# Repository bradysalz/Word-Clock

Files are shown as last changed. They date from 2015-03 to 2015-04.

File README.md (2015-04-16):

# Word-Clock
MSP430 based Word Clock for my GE423 HW Project. Decided to make it more of a "word search" than a simple light up clock. Tells the time in five minute intervals. 

## Description
First thing to do is program the init script for the RTC. A backup coin cell battery will make sure it shouldn't need to be re-calibrated for another 15 years (approximate). In normal mode, the MSP430 wakes from sleep and pings the RTC approximately every minute. This occurs by doing several I2C register reads from the device. Each of the "words" (listed below) is an LED load with one LED per letter, and the entire word is turned on/off by a transistor (n-channel FET). All of the 21 words' transistor gates are driven by three 8-bit daisy-chained serial-parallel shift registers. Once the RTC data is parsed, it is converted and shifted out to light up the appropriate phrasing. 

We also have a button available on the MSP430 that will open and close shades on the front of the clock via two servo motors. I eventually plan to automate this based on a custom alarm or light sensor. 

### Words
- Minutes
    - Five
    - Ten
    - Quarter
    - Twenty
    - Half
        
+ Phrases
    + Past
    + To
    + It Is
    + O Clock

As well as the hours One through Twelve. 

### To Do
- [x] Outline letters
- [x] Design Schematic
- [x] Design PCB
- [x] Code MSP430 RTC reads
- [x] Code MSP430 shift register writes
- [x] Code MSP430 servo drivers
- [x] Design physical enclosure
- [ ] Build physical enclosure
- [ ] Wire LEDs/resistors
- [ ] Add curtains

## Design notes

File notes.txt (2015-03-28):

total: 
21 'phrases'
91 letters
5 minute intervals (5/10/15/20/25/30) [+1 for none, +1 for 20+5]
12 hour intervals

longest sentence:
it is twenty five past eleven o clock
30 LED's simulataneously

max power budgeting:
LED: 30 x 0.03 A = 0.9
uC: 100mA~

bought:
RTC [BQ32002]
32.168kHz crystal
3.3v regulator 
shift registers 
FETs
usb connector

need2buy:
resistors
headers

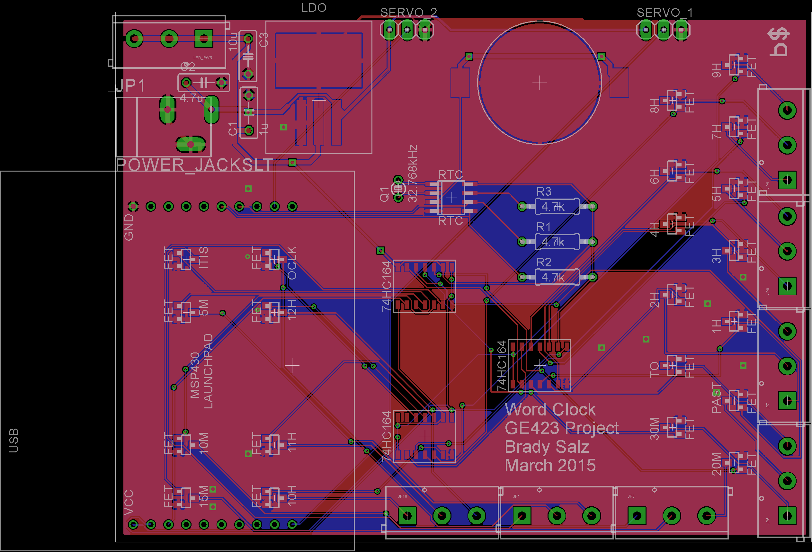
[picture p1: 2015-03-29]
hardware/WordClock_PCB.png

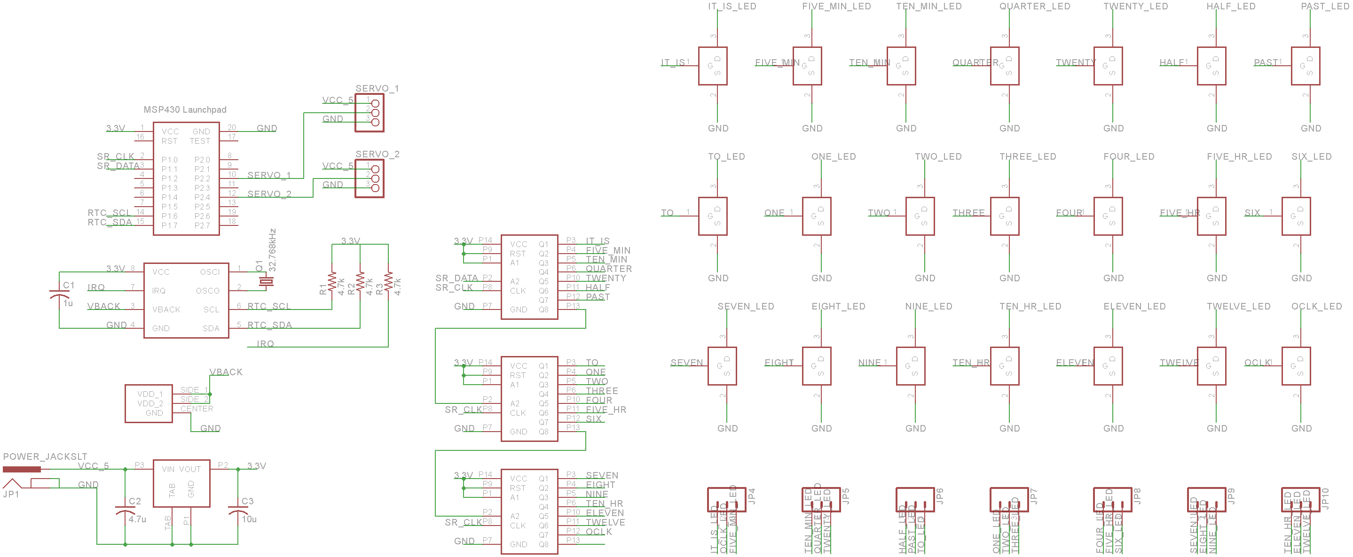
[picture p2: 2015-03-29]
hardware/WordClock_SCH.png

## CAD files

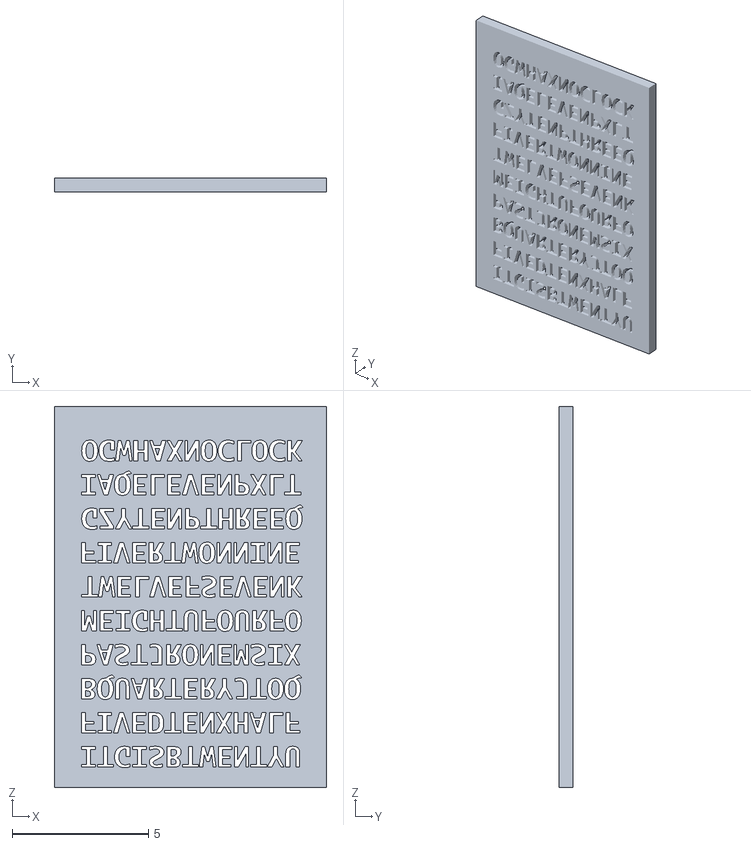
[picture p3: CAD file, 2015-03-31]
mechanical/word_clock.stl
10.0 x 0.5 x 14.0

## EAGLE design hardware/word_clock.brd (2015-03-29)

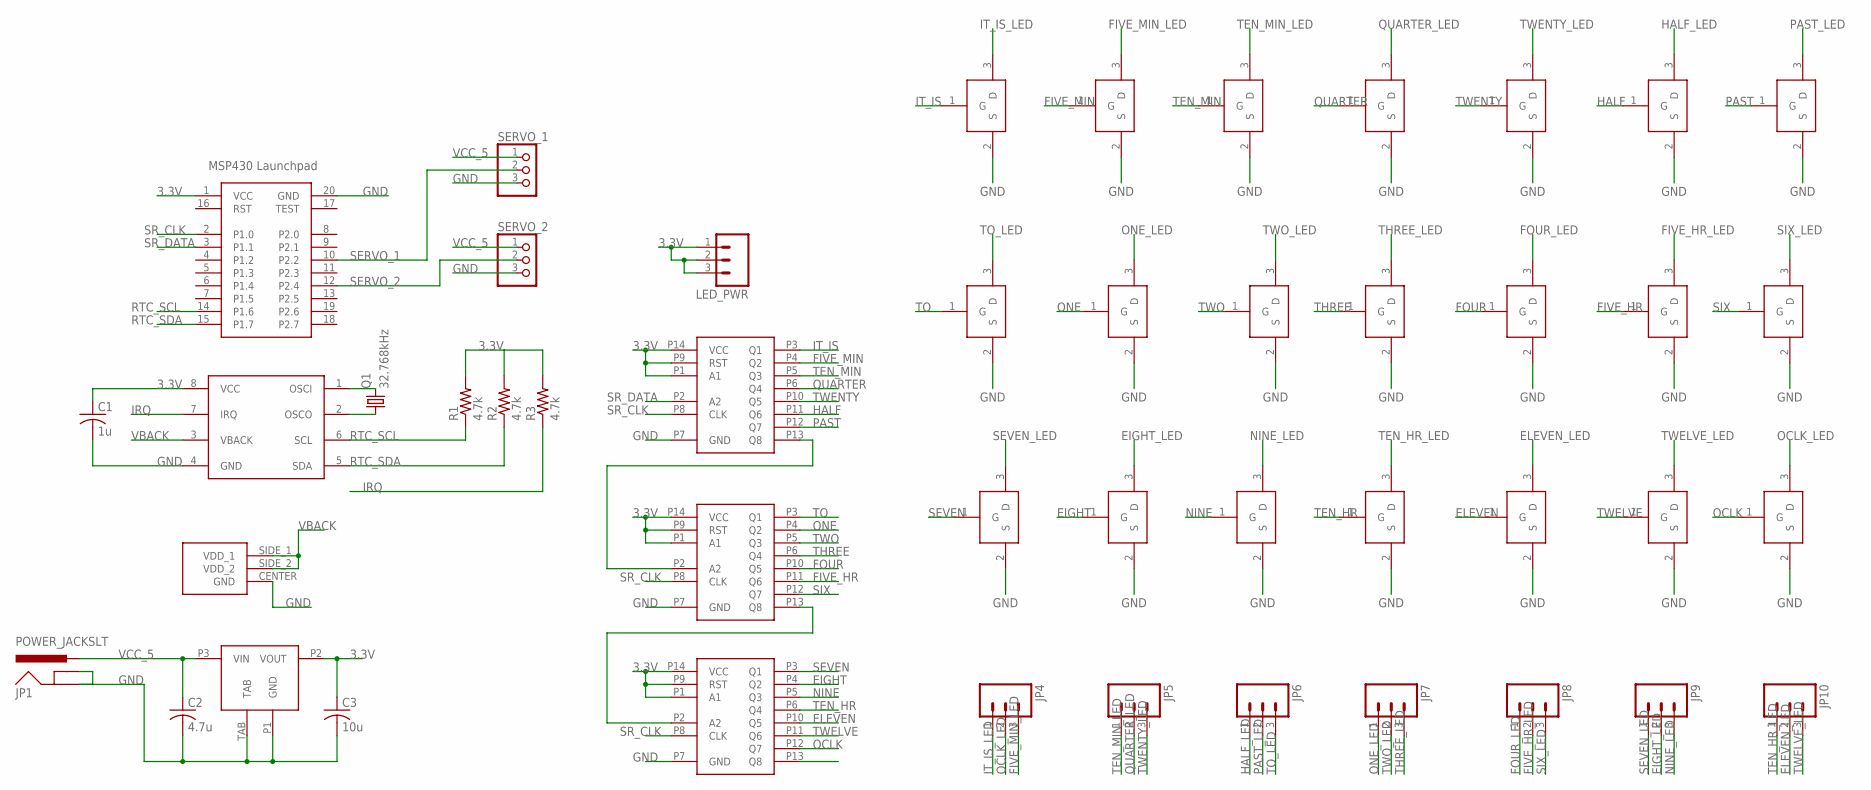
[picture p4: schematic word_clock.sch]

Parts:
1H, 2H, 3H, 4H, 5H, 5M, 6H, 7H, 8H, 9H, 10H, 10M, 11H, 12H, 15M, 20M, 30M: FET; SOT23
C1: 1u; C050-025X075
C2: 4.7u; C050-025X075
C3: 10u; C050-025X075
ITIS: FET; SOT23
JP1: POWER_JACKSLT; POWER_JACK_SLOT
JP4, JP5, JP6, JP7, JP8, JP9, JP10: M03-SCREW-5MM; SCREWTERMINAL-5MM-3
LED_PWR: M03-SCREW-5MM; SCREWTERMINAL-5MM-3
OCLK: FET; SOT23
PAST: FET; SOT23
Q1: 32.768kHz; TC26V
R1, R2, R3: 4.7k; 0207/10
RTC: RTC; SOIC8
SERVO_1, SERVO_2: PINHD-1X3; 1X03
SR_1, SR_2: SHIFT_REGISTER
TO: FET; SOT23
U$1: SHIFT_REGISTER
U$4: LDO
U$25: MSP430
U$28: COIN_CELL_SPARKFUN

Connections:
3.3V: C1.1, C3.1, LED_PWR.1, LED_PWR.2, LED_PWR.3, R1.2, R2.2, R3.2, RTC.8 (VCC), SR_1.P1 (A1), SR_1.P9 (RST), SR_1.P14 (VCC), SR_2.P1 (A1), SR_2.P9 (RST), SR_2.P14 (VCC), U$1.P1 (A1), U$1.P9 (RST), U$1.P14 (VCC), U$4.P2 (VOUT), U$25.1 (VCC)
EIGHT: 8H.1 (G), U$1.P4 (Q2)
EIGHT_LED: 8H.3 (D), JP9.2
ELEVEN: 11H.1 (G), U$1.P10 (Q5)
ELEVEN_LED: 11H.3 (D), JP10.2
FIVE_HR: 5H.1 (G), SR_2.P11 (Q6)
FIVE_HR_LED: 5H.3 (D), JP8.2
FIVE_MIN: 5M.1 (G), SR_1.P4 (Q2)
FIVE_MIN_LED: 5M.3 (D), JP4.3
FOUR: 4H.1 (G), SR_2.P10 (Q5)
FOUR_LED: 4H.3 (D), JP8.1
GND: 1H.2 (S), 2H.2 (S), 3H.2 (S), 4H.2 (S), 5H.2 (S), 5M.2 (S), 6H.2 (S), 7H.2 (S), 8H.2 (S), 9H.2 (S), 10H.2 (S), 10M.2 (S), 11H.2 (S), 12H.2 (S), 15M.2 (S), 20M.2 (S), 30M.2 (S), C1.2, C2.2, C3.2, ITIS.2 (S), JP1.GND@1 (GNDBREAK), JP1.GND@2 (GND), OCLK.2 (S), PAST.2 (S), RTC.4 (GND), SERVO_1.3, SERVO_2.3, SR_1.P7 (GND), SR_2.P7 (GND), TO.2 (S), U$1.P7 (GND), U$4.P1 (GND), U$4.TAB, U$25.20 (GND), U$28.CENTER (GND)
HALF: 30M.1 (G), SR_1.P11 (Q6)
HALF_LED: 30M.3 (D), JP6.1
IRQ: R3.1, RTC.7 (IRQ)
IT_IS: ITIS.1 (G), SR_1.P3 (Q1)
IT_IS_LED: ITIS.3 (D), JP4.1
unnamed: Q1.1, RTC.2 (OSCO)
unnamed: Q1.2, RTC.1 (OSCI)
unnamed: SR_1.P13 (Q8), SR_2.P2 (A2)
unnamed: SR_2.P13 (Q8), U$1.P2 (A2)
NINE: 9H.1 (G), U$1.P5 (Q3)
NINE_LED: 9H.3 (D), JP9.3
OCLK: OCLK.1 (G), U$1.P12 (Q7)
OCLK_LED: JP4.2, OCLK.3 (D)
ONE: 1H.1 (G), SR_2.P4 (Q2)
ONE_LED: 1H.3 (D), JP7.1
PAST: PAST.1 (G), SR_1.P12 (Q7)
PAST_LED: JP6.2, PAST.3 (D)
QUARTER: 15M.1 (G), SR_1.P6 (Q4)
QUARTER_LED: 15M.3 (D), JP5.2
RTC_SCL: R1.1, RTC.6 (SCL), U$25.14 (P1.6)
RTC_SDA: R2.1, RTC.5 (SDA), U$25.15 (P1.7)
SERVO_1: SERVO_1.2, U$25.10 (P2.2)
SERVO_2: SERVO_2.2, U$25.12 (P2.4)
SEVEN: 7H.1 (G), U$1.P3 (Q1)
SEVEN_LED: 7H.3 (D), JP9.1
SIX: 6H.1 (G), SR_2.P12 (Q7)
SIX_LED: 6H.3 (D), JP8.3
SR_CLK: SR_1.P8 (CLK), SR_2.P8 (CLK), U$1.P8 (CLK), U$25.2 (P1.0)
SR_DATA: SR_1.P2 (A2), U$25.3 (P1.1)
TEN_HR: 10H.1 (G), U$1.P6 (Q4)
TEN_HR_LED: 10H.3 (D), JP10.1
TEN_MIN: 10M.1 (G), SR_1.P5 (Q3)
TEN_MIN_LED: 10M.3 (D), JP5.1
THREE: 3H.1 (G), SR_2.P6 (Q4)
THREE_LED: 3H.3 (D), JP7.3
TO: SR_2.P3 (Q1), TO.1 (G)
TO_LED: JP6.3, TO.3 (D)
TWELVE: 12H.1 (G), U$1.P11 (Q6)
TWELVE_LED: 12H.3 (D), JP10.3
TWENTY: 20M.1 (G), SR_1.P10 (Q5)
TWENTY_LED: 20M.3 (D), JP5.3
TWO: 2H.1 (G), SR_2.P5 (Q3)
TWO_LED: 2H.3 (D), JP7.2
VBACK: RTC.3 (VBACK), U$28.SIDE_1 (VDD_1), U$28.SIDE_2 (VDD_2)
VCC_5: C2.1, JP1.PWR, SERVO_1.1, SERVO_2.1, U$4.P3 (VIN)

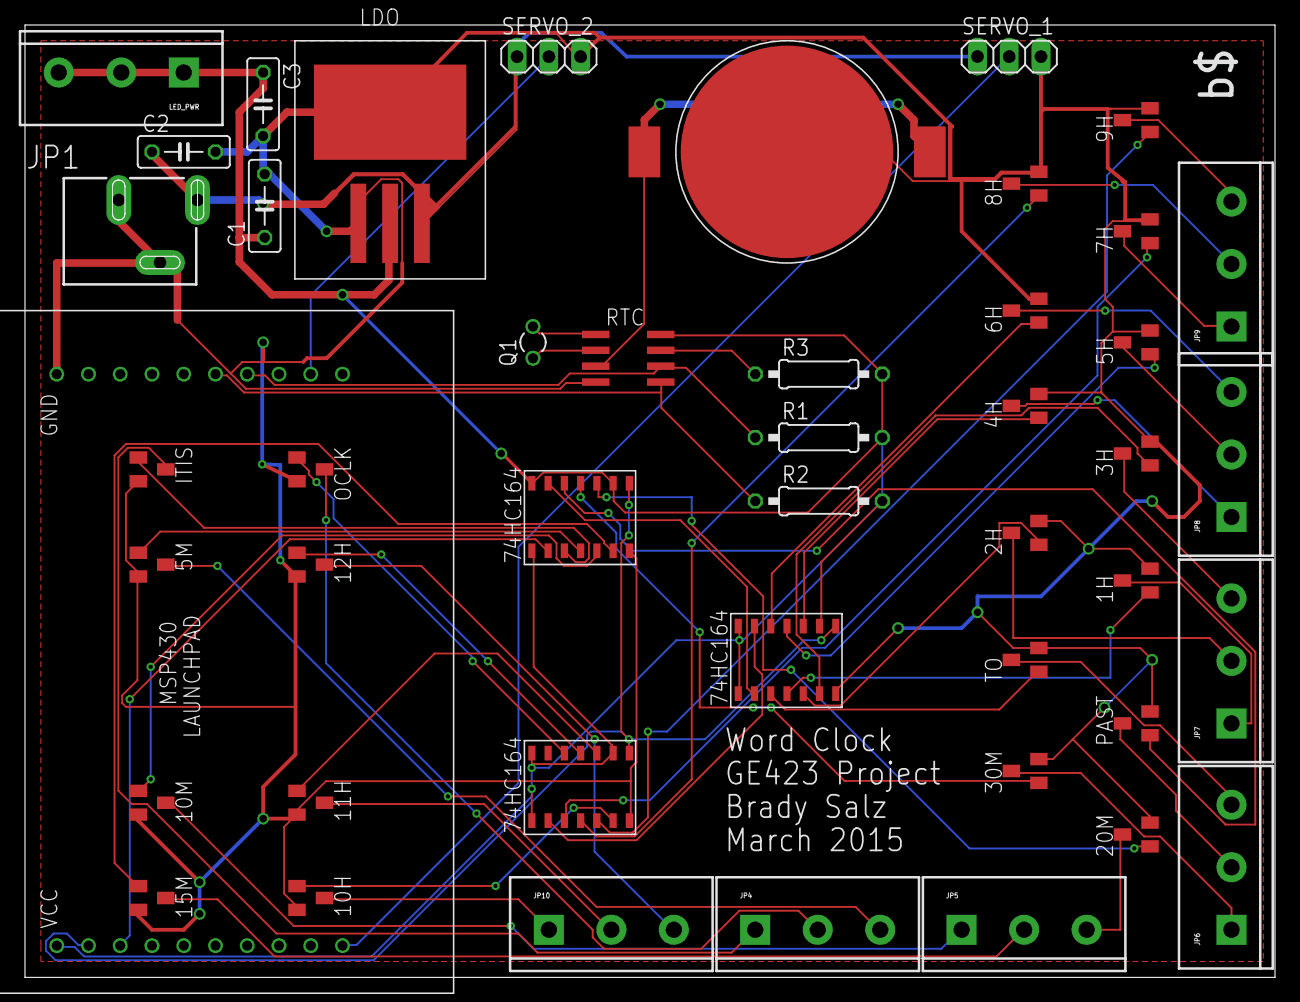
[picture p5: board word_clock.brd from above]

Board: 2 copper layers, 100.0 x 76.2 mm, 46 parts (0 on the bottom side), 57 nets.

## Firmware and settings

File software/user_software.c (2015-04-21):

/******************************************************************************
WORD CLOCK Controller
Brady Salz
GE423 HW Project
4/16/15

Template Code made by:
GE 423  - Dan Block
        Spring(2012)

        Written(by) : Steve(Keres)
College of Engineering Control Systems Lab
University of Illinois at Urbana-Champaign
*******************************************************************************/

#include "msp430g2553.h"
#include "UART.h"

// my local defns for calculating LED output
#define IT_IS    0x0000001
#define FIVE_MIN 0x0000002
#define TEN_MIN  0x0000004
#define QUARTER  0x0000008
#define TWENTY   0x0000010
#define HALF     0x0000020
#define PAST     0x0000040
#define TO       0x0000080
#define ONE      0x0000100
#define TWO      0x0000200
#define THREE    0x0000400
#define FOUR     0x0000800
#define FIVE_HR  0x0001000
#define SIX      0x0002000
#define SEVEN    0x0004000
#define EIGHT    0x0008000
#define NINE     0x0100000
#define TEN_HR   0x0200000
#define ELEVEN   0x0400000
#define TWELVE   0x0800000
#define OCLK     0x1000000

// register maps
#define REG_SECONDS 0x00
#define REG_MINUTES 0x01
#define REG_HOURS   0x02

// current time
// NEEDS TO BE CUSTOMIZED EACH TIME
// 0 - [3 bit BCD Ten's Second] - [4 bit BCD One's Second]
// 0 - [3 bit BCD Ten's Minute] - [4 bit BCD One's Minute]
// 0 - 0 - [2 bit BCD Ten's Hour] - [4 bit BCD One's Hour]
// use 24 hour format
unsigned char CURR_SEC = 0;
unsigned char CURR_MIN = 0;
unsigned char CURR_HRS = 0;

// globals
char newprint = 0;           // UART print flag
unsigned long timecnt = 0;  
unsigned char seconds = 0; 
unsigned char minutes = 0;
unsigned char hours = 0;

// function definitions
void config(void);
void pulseClk(void);
void shiftData(double wordArray);
void idle(int us);
void setRegister(unsigned char address, unsigned char value);
unsigned char getRegister(unsigned char address);
void calibrate(void);
double setLEDBits(void);
void setServoPos(void);

void main(void) {

    Init_UART(9600,1);  // Initialize UART for 9600 baud serial communication

    _BIS_SR(GIE);       // Enable global interrupt

    // check to see if inital cal needs to be performed
    if (getRegister(REG_MINUTES) & 0x80) 
    {
        calibrate();
    }

    while(1) 
    {
        if (newprint)  
        {   
            seconds = getRegister(REG_SECONDS);
            if(seconds & 0x80)
            {
                calibrate();
            }

            minutes = getRegister(REG_MINUTES);
            hours   = getRegister(REG_HOURS);

            double wordArray = IT_IS + OCLK;  //  intialize array 

            // convert from register to decimal
            minutes = (minutes & 0x0F) + 10 * (minutes>>4); 
            hours = (hours & 0x0F) + 10 * (hours>>4);      
            
            if (hours > 12) 
            {
                hours -= 12; // convert from 24hr to 12hr
            }

            UART_printf("Current time is %02d:%02d\r\n", hours, minutes);

            wordArray = setLEDBits();

            setServoPos();

            shiftData(wordArray);
        }
    }
}


// Timer A0 interrupt service routine
#pragma vector=TIMER0_A0_VECTOR
__interrupt void Timer_A (void)
{
    timecnt++; // Keep track of time for main while loop. 

    if ((timecnt%5000) == 0) {
        newprint = 1;  // flag main while loop that 15 seconds have gone by.  
        timecnt = 0;
    }

}

// USCI Transmit ISR - Called when TXBUF is empty (ready to accept another character)
#pragma vector=USCIAB0TX_VECTOR
__interrupt void USCI0TX_ISR(void) {

    if(IFG2&UCA0TXIFG) {        // USCI_A0 requested TX interrupt
        if(printf_flag) {
            if (currentindex == txcount) {
                senddone = 1;
                printf_flag = 0;
                IFG2 &= ~UCA0TXIFG;
            } else {
                UCA0TXBUF = printbuff[currentindex];
                currentindex++;
            }
        } else if(UART_flag) {
            if(!donesending) {
                UCA0TXBUF = txbuff[txindex];
                if(txbuff[txindex] == 255) {
                    donesending = 1;
                    txindex = 0;
                }
                else txindex++;
            }
        } else {  // interrupt after sendchar call so just set senddone flag since only one char is sent
            senddone = 1;
        }

        IFG2 &= ~UCA0TXIFG;
    }

    if(IFG2&UCB0TXIFG) {    // USCI_B0 requested TX interrupt (UCB0TXBUF is empty)

        IFG2 &= ~UCB0TXIFG;   // clear IFG
    }
}


// USCI Receive ISR - Called when shift register has been transferred to RXBUF
// Indicates completion of TX/RX operation
#pragma vector=USCIAB0RX_VECTOR
__interrupt void USCI0RX_ISR(void) 
{
    if(IFG2&UCB0RXIFG)  // USCI_B0 requested RX interrupt (UCB0RXBUF is full)
    {
        IFG2 &= ~UCB0RXIFG;   // clear IFG
    }

    if(IFG2&UCA0RXIFG)  // USCI_A0 requested RX interrupt (UCA0RXBUF is full)
    {
        IFG2 &= ~UCA0RXIFG;
    }
}


// set the configuration registers
// specifically focused on I2C, UART, UART 
void config(void)
{
    WDTCTL = WDTPW + WDTHOLD;                 // Stop WDT

    if (CALBC1_16MHZ ==0xFF || CALDCO_16MHZ == 0xFF) while(1);

    DCOCTL = CALDCO_16MHZ;    // Set uC to run at approximately 16 Mhz
    BCSCTL1 = CALBC1_16MHZ; 

    // Timer A Config
    TACCTL0 = CCIE;             // Enable Periodic interrupt
    TACCR0 = 16000;                // period = 1ms   
    TACTL = TASSEL_2 + MC_1; // source SMCLK, up mode

    // I2C Config
    P1SEL |= BIT6 + BIT7;   // Assign I2C pins to USCI_B0
    P1SEL2|= BIT6 + BIT7;   // Assign I2C pins to USCI_B0

    UCB0I2CSA = 0x68; // slave address (110 1000)
    UCB0CTL1 |= UCSWRST;                      // Enable SW reset
    UCB0CTL0 = UCMST + UCMODE_3 + UCSYNC;     // I2C Master, synchronous mode
    UCB0CTL1 = UCSSEL_2 + UCSWRST;            // Use SMCLK, keep SW reset, 7 bit
    UCB0BR0 = 12;                             // fSCL = SMCLK/12 = ~100kHz
    UCB0BR1 = 0;
    UCB0CTL1 &= ~UCSWRST; // start state machine
    IFG2 &= ~UCB0RXIE;    // clear interrupt flag, ready to Rx/Tx

    // GPIO Config
    P1DIR |= BIT1 + BIT0;    // shift register pins (1.1, 1.2) are outputs
    P1OUT = 0;              
    P1OUT |= BIT2;   // enable pullup for input
    P1REN |= BIT2;   // 1.3 is button input

    // Timer pin output setup
    P2SEL = 0x14;
    P2SEL2 = 0;
    P2DIR = 0x14;

    // PWM configuration
    TA1CTL = ID_3 + MC_1 + TASSEL_2;
    TA1CCR0 = 40000;
    TA1CCTL1 = OUTMOD_7;
    TA1CCTL2 = OUTMOD_7;

}


// create a rising edge pulse for the shift register
// shouldn't need any delay in this
void pulseClk(void)
{
    P1OUT &= ~BIT0;
    P1OUT |= BIT1;
    idle(5);
    P1OUT &= ~BIT0;
    idle(5);
}


// add a small delay
// used to delay while the chip processes the I2C data
// before TX/RX any more data
void idle(int us)
{
    us *= 16; // 16MHz clock
    int delay;
    for(delay = 0; delay < us; delay++);
}

// I2C Write
// set a register on the chip using I2C
void setRegister(unsigned char address, unsigned char value)
{
    UCB0CTL1 |= UCTXSTT + UCTR;       // generate start condition in transmit mode
    
    UCB0TXBUF = address & 0xFF;       // send address
    while(UCB0CTL1 & UCTXSTT);        // wait until start condition is sent
    while((!UCB0STAT & UCNACKIFG) && (!IFG2 & UCB0TXIFG)); // wait for ACK
    idle(15); // idle to wait for transfer to finish


    UCB0TXBUF = value & 0xFF;
    while((!UCB0STAT & UCNACKIFG) && (!IFG2 & UCB0TXIFG)); // wait for ACK
    idle(15); // idle to wait for transfer to finish

    UCB0CTL1 |= UCTXSTP;        //send stop condition after 2 byte of data
    while(UCB0CTL1 & UCTXSTP); //wait for stop condition to sent before moving on
}

// I2C Read
// get a register on the chip using I2C
unsigned char getRegister(unsigned char address)
{
    UCB0CTL1 |= UCTXSTT + UCTR;       // generate start condition in transmit mode
    
    UCB0TXBUF = (address) & 0xFF;   // send addresss
    while(UCB0CTL1 & UCTXSTT);      // wait until start condition is sent
    while((!UCB0STAT & UCNACKIFG) && (!IFG2 & UCB0TXIFG)); // wait for ACK
    idle(15);//idle to wait for transfer to finish

    //Recieve
    UCB0CTL1 &= ~UCTR;          //receive
    UCB0CTL1 |= UCTXSTT;        //send another start condition in receive mode
    idle(15);
    while(UCB0CTL1 & UCTXSTT);  //wait until start condition is sent

    UCB0CTL1 |= UCTXSTP;        //send stop condition after 1 byte of data
    while(!IFG2  & UCB0RXIFG);  //wait for master to finish receiving
    idle(15);

    unsigned char value = UCB0RXBUF;
    while(UCB0CTL1 & UCTXSTP); //wait for stop condition to sent before moving on
    return value;
}

void calibrate(void)
{
    setRegister(REG_SECONDS, CURR_SEC);
    setRegister(REG_MINUTES, CURR_MIN);
    setRegister(REG_HOURS, CURR_HRS);
}

void shiftData(double wordArray)
{
    // shift out LSB first
    int i;
    for(i = 20; i >= 0; i--)
    {
        if( (int) wordArray>>i & 0x01) // need to cast for if statement
        {
            P1OUT |= BIT1;
        }       
        else
        {
            P1OUT &= ~BIT1;
        }
        pulseClk();
    }
}

double setLEDBits(void)
{
    wordArray = 0;

    if ((3 <= minutes) && (minutes <= 7))
    {
        wordArray += FIVE_MIN;
        wordArray += PAST;
    }
    else if ((8 <= minutes) && (minutes <= 12))
    {
        wordArray += TEN_MIN;
        wordArray += PAST;
    }
    else if ((13 <= minutes) && (minutes <= 17))
    {
        wordArray += QUARTER;
        wordArray += PAST;
    }
    else if ((18 <= minutes) && (minutes <= 22))
    {
        wordArray += TWENTY;
        wordArray += PAST;
    }
    else if ((23 <= minutes) && (minutes <= 27))
    {
        wordArray += (TWENTY + FIVE_MIN);
        wordArray += PAST;
    }
    else if ((27 <= minutes) && (minutes <= 32))
    {
        wordArray += HALF;
        wordArray += PAST;
    }
    else if ((33 <= minutes) && (minutes <= 37))
    {
        wordArray += (TWENTY + FIVE_MIN);
        wordArray += TO;
    }
    else if ((38 <= minutes) && (minutes <= 42))
    {
        wordArray += TWENTY;
        wordArray += TO;
    }
    else if ((43 <= minutes) && (minutes <= 47))
    {
        wordArray += QUARTER;
        wordArray += TO;
    }
    else if ((48 <= minutes) && (minutes <= 52))
    {
        wordArray += TEN_MIN;
        wordArray += TO;
    }
    else if ((53 <= minutes) && (minutes <= 57))
    {
        wordArray += FIVE_MIN;
        wordArray += TO;
    }

    switch (hours)
    {
        case 0:
            wordArray += TWELVE;
            break;

        case 1:
            wordArray += ONE;
            break;

        case 2:
            wordArray += TWO;
            break;

        case 3:
            wordArray += THREE;
            break;

        case 4:
            wordArray += FOUR;
            break;

        case 5:
            wordArray += FIVE_HR;
            break;

        case 6:
            wordArray += SIX;
            break;

        case 7:
            wordArray += SEVEN;
            break;

        case 8:
            wordArray += EIGHT;
            break;

        case 9:
            wordArray += NINE;
            break;

        case 10:
            wordArray += TEN_HR;
            break;

        case 11:
            wordArray += ELEVEN;
            break;

        case 12:
            wordArray += TWELVE;
            break;
    }

    return wordArray;
}

void setServoPos()
{
    // minutes   = [0 ->60]
    // servoTurn = [3 -> 14]
    // tranform by:
    // scale 0->1
    // scale 0->11
    // move 3->14
    // turns 0 to 180(ish)
    
    // minutes ranges 
    float servoTurn = minutes/60.0*11.0 + 3

    TA1CCR1 = servoTurn*40000L/100;
    TA1CCR2 = servoTurn*40000L/100;
        
}

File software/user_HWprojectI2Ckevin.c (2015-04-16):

/******************************************************************************
MSP430G2553 Project Creator

GE 423  - Dan Block
        Spring(2012)

        Written(by) : Steve(Keres)
College of Engineering Control Systems Lab
University of Illinois at Urbana-Champaign
*******************************************************************************/

#include "msp430g2553.h"
#include "UART.h"
#define VL6180x_FAILURE_RESET  -1

#define VL6180X_IDENTIFICATION_MODEL_ID              0x0000
#define VL6180X_IDENTIFICATION_MODEL_REV_MAJOR       0x0001
#define VL6180X_IDENTIFICATION_MODEL_REV_MINOR       0x0002
#define VL6180X_IDENTIFICATION_MODULE_REV_MAJOR      0x0003
#define VL6180X_IDENTIFICATION_MODULE_REV_MINOR      0x0004
#define VL6180X_IDENTIFICATION_DATE                  0x0006 //16bit value
#define VL6180X_IDENTIFICATION_TIME                  0x0008 //16bit value

#define VL6180X_SYSTEM_MODE_GPIO0                    0x0010
#define VL6180X_SYSTEM_MODE_GPIO1                    0x0011
#define VL6180X_SYSTEM_HISTORY_CTRL                  0x0012
#define VL6180X_SYSTEM_INTERRUPT_CONFIG_GPIO         0x0014
#define VL6180X_SYSTEM_INTERRUPT_CLEAR               0x0015
#define VL6180X_SYSTEM_FRESH_OUT_OF_RESET            0x0016
#define VL6180X_SYSTEM_GROUPED_PARAMETER_HOLD        0x0017

#define VL6180X_SYSRANGE_START                       0x0018
#define VL6180X_SYSRANGE_THRESH_HIGH                 0x0019
#define VL6180X_SYSRANGE_THRESH_LOW                  0x001A
#define VL6180X_SYSRANGE_INTERMEASUREMENT_PERIOD     0x001B
#define VL6180X_SYSRANGE_MAX_CONVERGENCE_TIME        0x001C
#define VL6180X_SYSRANGE_CROSSTALK_COMPENSATION_RATE 0x001E
#define VL6180X_SYSRANGE_CROSSTALK_VALID_HEIGHT      0x0021
#define VL6180X_SYSRANGE_EARLY_CONVERGENCE_ESTIMATE  0x0022
#define VL6180X_SYSRANGE_PART_TO_PART_RANGE_OFFSET   0x0024
#define VL6180X_SYSRANGE_RANGE_IGNORE_VALID_HEIGHT   0x0025
#define VL6180X_SYSRANGE_RANGE_IGNORE_THRESHOLD      0x0026
#define VL6180X_SYSRANGE_MAX_AMBIENT_LEVEL_MULT      0x002C
#define VL6180X_SYSRANGE_RANGE_CHECK_ENABLES         0x002D
#define VL6180X_SYSRANGE_VHV_RECALIBRATE             0x002E
#define VL6180X_SYSRANGE_VHV_REPEAT_RATE             0x0031

#define VL6180X_SYSALS_START                         0x0038
#define VL6180X_SYSALS_THRESH_HIGH                   0x003A
#define VL6180X_SYSALS_THRESH_LOW                    0x003C
#define VL6180X_SYSALS_INTERMEASUREMENT_PERIOD       0x003E
#define VL6180X_SYSALS_ANALOGUE_GAIN                 0x003F
#define VL6180X_SYSALS_INTEGRATION_PERIOD            0x0040

#define VL6180X_RESULT_RANGE_STATUS                  0x004D
#define VL6180X_RESULT_ALS_STATUS                    0x004E
#define VL6180X_RESULT_INTERRUPT_STATUS_GPIO         0x004F
#define VL6180X_RESULT_ALS_VAL                       0x0050
#define VL6180X_RESULT_HISTORY_BUFFER                0x0052
#define VL6180X_RESULT_RANGE_VAL                     0x0062
#define VL6180X_RESULT_RANGE_RAW                     0x0064
#define VL6180X_RESULT_RANGE_RETURN_RATE             0x0066
#define VL6180X_RESULT_RANGE_REFERENCE_RATE          0x0068
#define VL6180X_RESULT_RANGE_RETURN_SIGNAL_COUNT     0x006C
#define VL6180X_RESULT_RANGE_REFERENCE_SIGNAL_COUNT  0x0070
#define VL6180X_RESULT_RANGE_RETURN_AMB_COUNT        0x0074
#define VL6180X_RESULT_RANGE_REFERENCE_AMB_COUNT     0x0078
#define VL6180X_RESULT_RANGE_RETURN_CONV_TIME        0x007C
#define VL6180X_RESULT_RANGE_REFERENCE_CONV_TIME     0x0080

#define VL6180X_READOUT_AVERAGING_SAMPLE_PERIOD      0x010A
#define VL6180X_FIRMWARE_BOOTUP                      0x0119
#define VL6180X_FIRMWARE_RESULT_SCALER               0x0120
#define VL6180X_I2C_SLAVE_DEVICE_ADDRESS             0x0212
#define VL6180X_INTERLEAVED_MODE_ENABLE              0x02A3

int version = 0,distance=0;


char newprint = 0;
int failure=0;
unsigned long timecnt = 0;  
char toggle=0;
int g_i = 0;
// Idle function
void idle(int us)
{
  us = 16*us;
  for(g_i=0;g_i<us;g_i++);
}


void setRegister(unsigned int address, unsigned char value) {
	//Transmit address
	UCB0CTL1 |= UCTXSTT + UCTR;   	//generate start condition in transmit mode
	UCB0TXBUF = (address>>8) & 0xFF;				//send memory location
	while(UCB0CTL1 & UCTXSTT);		//wait until start condition is sent
	while((!UCB0STAT & UCNACKIFG) && (!IFG2 & UCB0TXIFG)); //wait for slave to acknowledge and master to finish transmitting
	idle(15);//idle to wait for transfer to finish
	//Transmit data
	UCB0TXBUF = (address) & 0xFF;
	while((!UCB0STAT & UCNACKIFG) && (!IFG2 & UCB0TXIFG)); //wait for slave to acknowledge and master to finish transmitting
	idle(15);//idle to wait for transfer to finish

	UCB0TXBUF = (value) & 0xFF;
	while((!UCB0STAT & UCNACKIFG) && (!IFG2 & UCB0TXIFG)); //wait for slave to acknowledge and master to finish transmitting
	idle(15);//idle to wait for transfer to finish

	UCB0CTL1 |= UCTXSTP;        //send stop condition after 2 byte of data
	while(UCB0CTL1 & UCTXSTP); //wait for stop condition to sent before moving on

}

unsigned char getRegister(unsigned int address) {
	//Transmit address
	UCB0CTL1 |= UCTXSTT + UCTR;   	//generate start condition in transmit mode
	UCB0TXBUF = (address>>8) & 0xFF;				//send memory location
	while(UCB0CTL1 & UCTXSTT);		//wait until start condition is sent
	while((!UCB0STAT & UCNACKIFG) && (!IFG2 & UCB0TXIFG)); //wait for slave to acknowledge and master to finish transmitting
	idle(15);//idle to wait for transfer to finish
	//Transmit data
	UCB0TXBUF = (address) & 0xFF;
	while((!UCB0STAT & UCNACKIFG) && (!IFG2 & UCB0TXIFG)); //wait for slave to acknowledge and master to finish transmitting
	idle(15);//idle to wait for transfer to finish

	//Recieve
	UCB0CTL1 &= ~UCTR;			//receive
	UCB0CTL1 |= UCTXSTT;		//send another start condition in receive mode
	idle(15);
	while(UCB0CTL1 & UCTXSTT);	//wait until start condition is sent
	UCB0CTL1 |= UCTXSTP;        //send stop condition after 1 byte of data
	while(!IFG2  & UCB0RXIFG);  //wait for master to finish receiving
	idle(15);
	unsigned char value = UCB0RXBUF;
	while(UCB0CTL1 & UCTXSTP); //wait for stop condition to sent before moving on
	return value;
}
void startDistance(void)
{
	setRegister(VL6180X_SYSRANGE_START, 0x01);
}
unsigned char readDistance(void)
{
	return getRegister(VL6180X_RESULT_RANGE_VAL);
}
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

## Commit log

2015-03-28 starting eagle schematic
    added all parts to eagle schematic
    [word_clock.sch]
2015-03-28 added eagle library
    added library i made with specific parts i used. usefulness probably
    near 0/10 but just in case
2015-03-29 initial board
    finished initial schematic
    laid out (no routing) first board
    [word_clock.brd, word_clock.sch]
2015-03-29 finished boards
    finally. added VCC rail for LEDs
    [word_clock.brd, word_clock.sch]
2015-03-29 fixed pcb picture
    definitely didn't upload 2 pics as .sch
2015-03-29 renamed directory
    changed to hardware to make it prettier 4 kashev
    [word_clock.brd, word_clock.sch]
2015-03-29 created msp430 skeleton
    thanks to dan block for the general skeleton code with basic
    main/interrupts/UART
2015-03-31 added STL file
    first iteration
    [word_clock.stl]
2015-04-08 remove extra interrupt UART
2015-04-16 demo I2C code
    thanks dan block
2015-04-16 more I2C config
2015-04-16 initial calibration
2015-04-16 initial control flow
2015-04-16 calibrate function
2015-04-16 moved current time comments
2015-04-21 moved ugly if/else/switch code to function
2015-04-21 adding servocode
2015-04-21 printf debugging

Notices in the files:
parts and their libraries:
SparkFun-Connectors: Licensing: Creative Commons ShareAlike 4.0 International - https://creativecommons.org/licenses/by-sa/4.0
